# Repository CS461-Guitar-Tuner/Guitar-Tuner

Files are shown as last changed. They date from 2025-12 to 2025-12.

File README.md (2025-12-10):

# Guitar-Tuner
This is the code for our guitar tuner. It can automatically tune a guitar automatically based on which pitch you wish it to be. In addition there is a mode to manually test if the string is in pitch.

This is a makeshift design and thus it is quite costly. This was done more in an attempt to learn how to create a product rather than be efficient.

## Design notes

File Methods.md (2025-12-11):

# Methods

This section describes how the guitar tuner was implemented, including hardware configuration, software architecture, pitch detection logic, user interaction, and motor automation. The goal is to clearly explain both what the system does and how it does it, so that another person could reproduce the prototype using this document.

---

## Hardware Overview and System Architecture

The system uses two microcontrollers:

- **Adafruit Circuit Playground Classic (CPC)** — main controller
- **Adafruit Circuit Playground Bluefruit (CPB)** — motor controller

The Classic handles microphone sampling, pitch detection, OLED display output, button input, and audio feedback. The Bluefruit is dedicated to controlling the tuning motor using PWM. This split prevents motor noise and timing issues from interfering with audio processing.

---

## Pin Assignments and Wiring

### Circuit Playground Classic

The external electret microphone is connected to analog pin A4:

```cpp
const int MIC_PIN = A4;
```

The OLED display (SSD1331) is connected via SPI:

```cpp
#define OLED_MOSI 2
#define OLED_CLK  3
#define OLED_CS   10
#define OLED_DC   9
#define OLED_RST  0
```

The on-board speaker is driven using:

```cpp
#define SPEAKER_PIN 1
```

Motor control signals sent to the Bluefruit:

```cpp
const int MOTOR_DIR_PIN = 12;   // direction
const int MOTOR_EN_PIN  = 6;    // enable
```

User interaction uses the built-in left and right buttons:
- Right button: cycle strings or modes
- Left button: confirm selection / return
- Both buttons held: power on/off

---

### Circuit Playground Bluefruit

Control inputs from the Classic:

```cpp
#define DIR_IN A5
#define EN_IN  A6
```

Motor driver outputs:

```cpp
#define AIN1 A1
#define AIN2 A2
#define SLP  A3
```

The Bluefruit reads direction and enable signals and converts them into PWM outputs that drive the DC motor through a motor driver.

---

## Software Libraries Used

### Circuit Playground Classic
- `math.h` — RMS calculation and logarithmic cents conversion
- `Adafruit_CircuitPlayground.h` — microphone, buttons, speaker
- `SPI.h` — SPI communication
- `Adafruit_SSD1331.h` — OLED driver
- `Adafruit_GFX.h` — graphics rendering
- `Fonts/TomThumb.h` — compact font to reduce memory usage

### Circuit Playground Bluefruit
- `Adafruit_TinyUSB.h` — USB and serial support

Adafruit examples were referenced for OLED setup and hardware initialization. 

---

## Guitar String Representation

Each guitar string is represented by a name and its target frequency:

```cpp
struct Note {
  const char* name;
  float freq;
};

Note strings[] = {
  {"E2", 82.41},
  {"A2", 110.00},
  {"D3", 146.83},
  {"G3", 196.00},
  {"B3", 246.94},
  {"E4", 329.63}
};
```

The currently selected string is changed using the right button.

---

## Pitch Detection and Autocorrelation Logic

The tuner uses a **time-domain autocorrelation-style algorithm** to estimate pitch. This approach was chosen because it is more robust than simple zero-crossing methods for guitar signals, which contain harmonics and background noise.

### Sampling Strategy

```cpp
const int N_SAMPLES = 250;
int16_t samples[N_SAMPLES];
```

The microphone signal is sampled `N_SAMPLES` times using `analogRead()`. The total sampling time is measured using `micros()` so the effective sample rate can be calculated dynamically rather than assumed.

### How Autocorrelation Is Used

1. **DC Offset Removal**  
   The average of all samples is subtracted so the waveform is centered around zero. This prevents bias from affecting pitch estimation.

2. **Noise Rejection (RMS Gate)**  
   The RMS energy of the signal is computed. If the RMS value is below a threshold, the signal is treated as silence and ignored.

3. **Lag Search (Autocorrelation)**  
   The algorithm searches over a range of delays (lags) corresponding to roughly 60–500 Hz, which covers the guitar’s frequency range.  For each lag, it computes the sum of      squared differences between the signal and a shifted version of itself. The lag with the smallest error represents the signal’s fundamental period.

4. **Frequency Calculation**  
   Frequency is computed as the sample rate divided by the best lag.

### Autocorrelation Code

```cpp
float measureFrequency() {
  //  Collect samples and measure sample rate
  unsigned long start = micros(); //take the first time measurement
  for (int i = 0; i < N_SAMPLES; i++) {
    samples[i] = analogRead(MIC_PIN);
  }
  unsigned long end = micros(); //take the second time measurement 
 
  float totalTimeSec = (end - start) / 1000000.0; //find the total time ellapsed in seconds 
  if (totalTimeSec <= 0) return 0.0; //mostly a worry if the timer is wrapping around-- just in case
  float sampleRate = N_SAMPLES / totalTimeSec; //gives us samples per second to be used in frequency calc 
 
  //  Remove DC offset and measure signal energy (centering the signal at zero)
  long sum = 0;
  for (int i = 0; i < N_SAMPLES; i++) {
    sum += samples[i]; //tallying up all of the samples so... 
  }
  float mean = sum / (float)N_SAMPLES; //mean is where the zero lies 
  double energy = 0.0; //reminder about what energy 
  for (int i = 0; i < N_SAMPLES; i++) {
    float v = samples[i] - mean;
    samples[i] = (int16_t)v;
    energy += v * v;
  }
  float rms = sqrt(energy / N_SAMPLES);
 
  // Simple noise gate so we don't react to nothing
  if (rms < 5.0) {   // tweak this threshold if needed
    return 0.0;
  }
 
  // Difference function in guitar range
  int minLag = (int)(sampleRate / 500.0); // ~500 Hz upper bound
  int maxLag = (int)(sampleRate / 60.0);  // ~60 Hz lower bound
 
  if (minLag < 2) minLag = 2;
  if (maxLag >= N_SAMPLES - 1) maxLag = N_SAMPLES - 2;
 
  float bestLag = -1;
  unsigned long bestDiff = 0xFFFFFFFF;
 
  for (int lag = minLag; lag <= maxLag; lag++) {
    unsigned long diff = 0;
 
    for (int i = 0; i < N_SAMPLES - lag; i++) {
      int32_t d = (int32_t)samples[i] - (int32_t)samples[i + lag];
      diff += (unsigned long)(d * d);
    }
 
    if (diff < bestDiff) {
      bestDiff = diff;
      bestLag = lag;
    }
  }
 
  if (bestLag <= 0) return 0.0;
 
  float freq = sampleRate / bestLag;
  return freq;
}
 
float centsOff(float measured, float target) {
  return 1200.0 * log(measured / target) / log(2.0);
}
 
const char* tuningStatus(float cents) {
  if (fabs(cents) < 5.0)  return "IN TUNE";
  if (cents < 0)          return "FLAT";
  return "SHARP";
}
```

---

## Cents Error and Tuning Classification

Pitch error is measured in **cents**, making tuning precision consistent across strings:

```cpp
float centsOff(float measured, float target) {
  return 1200.0 * log(measured / target) / log(2.0);
}
```

```cpp
const char* tuningStatus(float cents) {
  if (fabs(cents) < 5.0)  return "IN TUNE";
  if (cents < 0)          return "FLAT";
  return "SHARP";
}
```
In addition to the RMS noise gate, the tuner ignores detected pitches that are too far from the selected string’s target. Two thresholds are used.
```cpp
const float IN_TUNE_CENTS = 20.0;
const float MAX_DEVIATION_CENTS = 80.0;
```

If the absolute cents error exceeds MAX_DEVIATION_CENTS, the reading is discarded. This prevents background noise, adjacent strings, or unrelated sounds from affecting the display or driving the motor.

---

## State Machine and Modes

```cpp
enum MainState { OFF, WELCOME, SELECT, NORMAL, MOTOR, FORK };
```

- **Normal Mode:** visual tuner with OLED and audio feedback
- **Motor Mode:** automatically adjusts tuning peg
- **Fork Mode:** plays reference tone through speaker

### Motor Automation Logic

```cpp
void sendMotorCommand(float cents) {
  const float DEAD_ZONE = IN_TUNE_CENTS;

  if (fabs(cents) < DEAD_ZONE) {
    digitalWrite(MOTOR_EN_PIN, LOW);   // stop motor
    return;
  }

  bool tighten = (cents < 0);  // FLAT => tighten, SHARP => loosen
  digitalWrite(MOTOR_DIR_PIN, tighten ? HIGH : LOW);
  digitalWrite(MOTOR_EN_PIN, HIGH);
}

```
[Main MCU code](mainMCUcode.ino) |
[Helper MCU code](helperMCUcode.ino) |
[View General Pinout](assets/images/tuner_pinout.pdf) |
[View FSM](assets/images/tuner_fsm.pdf) |
<a href="assets/images/motor_to_peg_adapter.stl" download>3-D Peg Turner (.stl)</a>

---

<html lang="en">
<head>
  <meta charset="UTF-8" />
  <meta name="viewport" content="width=device-width, initial-scale=1.0" />
</head>

<body>

  <h2>Bill of Materials</h2>

  <p>
    These are all the components used throughout the project. 
    Alligator clips and connecting wires were provided.
    3-D printing was provided by Middlebury College.
  </p>

  <p><strong>Total budget:</strong> $150</p>

  <table border="1" cellspacing="0" cellpadding="6">
    <thead>
      <tr>
        <th>Item</th>
        <th>Supplier</th>
        <th>Quantity</th>
        <th>Total Cost</th>
      </tr>
    </thead>
    <tbody>
      <tr>
        <td><a href="https://www.adafruit.com/product/1063">Microphone</a></td>
        <td>Adafruit</td>
        <td>1</td>
        <td>$6.95</td>
      </tr>
      <tr>
        <td><a href="https://www.adafruit.com/product/4227">STEMMA Speaker Amp</a></td>
        <td>Adafruit</td>
        <td>1</td>
        <td>$1.95</td>
      </tr>
      <tr>
        <td><a href="https://www.adafruit.com/product/3777">Micro Servo Motor</a></td>
        <td>Adafruit</td>
        <td>1</td>
        <td>$2.95</td>
      </tr>
      <tr>
        <td><a href="https://www.adafruit.com/product/684">OLED Display</a></td>
        <td>Adafruit</td>
        <td>1</td>
        <td>$29.95</td>
      </tr>
      <tr>
        <td><a href="https://www.digikey.com/en/products/detail/hammond-manufacturing/BH4AAW/3869836">
          4xAA Battery Holder</a></td>
        <td>Digi-Key</td>
        <td>1</td>
        <td>$4.65</td>
      </tr>
      <tr>
        <td><a href="https://learn.adafruit.com/adafruit-circuit-playground-bluefruit">
          Circuit Playground Bluefruit</a></td>
        <td>Adafruit</td>
        <td>1</td>
        <td>$24.95</td>
      </tr>
      <tr>
        <td><a href="https://www.adafruit.com/product/3297">DC Motor Driver</a></td>
        <td>Adafruit</td>
        <td>1</td>
        <td>$5.95</td>
      </tr>
      <tr>
        <td><a href="https://www.adafruit.com/product/3000">Circuit Playground Classic</a></td>
        <td>Adafruit</td>
        <td>1</td>
        <td>$19.95</td>
      </tr>
      <tr>
        <td><strong>Total</strong></td>
        <td>—</td>
        <td>—</td>
        <td><strong>$97.30</strong></td>
      </tr>
    </tbody>
  </table>
</body>
</html>

[Introduction](introduction.md) |
[Methods](Methods.md) |
[Results](results.md) |
[Schedule](schedule.md) |
[Issues](issues.md) |
[Ethics](ethics.md) |
[Accessibility](accessibility.md) |
[References](references.md)

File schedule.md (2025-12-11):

# Planned Team Work Schedule

---

##  Weekly Timeline

### **Week 8**
- Wait for materials to arrive  
- Preemptively read datasheets and pinouts  
- Assemble the circuit board  

### **Weeks 9–10**
- Detect the correct tone  
- Implement a fully functional display  
- Make the motor turn the tuning peg  
- Occasional check-ins to ensure steady progress  

### **Week 11**
- System testing and debugging  

### **Week 12**
- Prepare final demo  
- Write project report  
- Prepare presentation  

---

## Task Breakdown by Responsibility

### **Board Assembly & Hardware Setup**
- Assemble the board  
- Determine how to connect each component by reading datasheets and pinouts  
- Identify correct operating voltages for all components  
- Determine required resistors to achieve target voltages  

---

### **Tone Detection & Signal Processing**
- Detect the correct tone from the guitar string  
- Read microphone input into the Circuit Playground  
- Detect which pitch the user is attempting to tune to  
- Determine whether the current pitch is sharp or flat  
- Communicate pitch information via Serial Port to a laptop as an initial proof of concept  
- Final goal: display pitch information directly on the OLED  

---

### **Display / UI Development (OLED)**
**Edy**

- Program and manage the OLED display  
- Display the detected pitch  
- Use color to indicate how close the tone is to being in tune  
- Show battery life status  

---

### **Motorized Tuning System**
**Gerson & Charlie**

- Automatically turn the motor based on detected pitch (Gerson)  
- Synchronize motor movement to the relative pitch of each string  
- Design a method to activate the motor  
  - Holding a button  
  - Automatic activation via microphone input  

---

### **Testing & Validation**
**Charlie**

- Bring a guitar and a commercial tuner for reference  
- Verify pitch accuracy against a known-good tuner  
- Test accuracy across different pitch ranges  
  - Lower strings  
  - Higher strings
---
 
### **Actuality of the Schedule**
- In the end our schedule ended up changing dramatically throughout the project. We simply met up when we were available and set goals dependant on the day. For example, we would schedule a meeting on simply learning how to turn on the display and work with making the microphone detect pitch. These meetings ended up being around 2-3 hours dependant on the task. There were times in which we were not able to finish the goal by the meeting so we would disperse and end up doing parts by ourselves. We have a fairly efficient workflow overall, however we did struggle a bit with scheduling things near the end due to underestimating certain tasks. Each of us ended up working on most of the components together, even more than expected.
- Edy and Gerson focused a lot of the oled, Gerson with figuring how to turn it on alongside the functionality, while Edy worked a lot on the UI and Gerson helped create a lot of the initial states of our machine.
- The group as a whole didn't figure out whether to use the external microphone or the internal one from the circuit playground till near the end due to the difficulties of making it function with the current setup.
- A lot of time near the end was spent combining the code from the components together to create two different sketches that functioned together without bugs. 

[Introduction](introduction.md) |
[Methods](Methods.md) |
[Results](results.md) |
[Schedule](schedule.md) |
[Issues](issues.md) |
[Ethics](ethics.md) |
[Accessibility](accessibility.md) |
[References](references.md)

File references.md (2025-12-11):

Tripoli, S. et al. (2023) Guide for I2C OLED display with Arduino, Random Nerd Tutorials. Available at: https://randomnerdtutorials.com/guide-for-oled-display-with-arduino/ (Accessed: 10 December 2025).

Rembor, K. Adafruit Circuit Playground Bluefruit, Adafruit Learning System. Available at: https://learn.adafruit.com/adafruit-circuit-playground-bluefruit (Accessed: 10 December 2025).

BH4AAW hammond manufacturing battery products, DigiKey. Available at: https://www.digikey.com/en/products/detail/hammond-manufacturing/BH4AAW/3869836 (Accessed: 10 December 2025).

Industries, A. DC gearbox motor - ‘Tt motor’ - 200RPM - 3 to 6VDC, adafruit industries blog RSS. Available at: https://www.adafruit.com/product/3777 (Accessed: 10 December 2025).

Industries, A. Mini oval speaker with short wires - 8 ohm 1 watt, adafruit industries blog RSS. Available at: https://www.adafruit.com/product/4227 (Accessed: 10 December 2025).

Industries, A. (no date b) Electret microphone amplifier - Max4466 with adjustable gain, adafruit industries blog RSS. Available at: https://www.adafruit.com/product/1063 (Accessed: 10 December 2025).

ChatGPT.” OpenAI, 2025, https://chat.openai.com/

[Introduction](introduction.md) |
[Methods](Methods.md) |
[Results](results.md) |
[Schedule](schedule.md) |
[Issues](issues.md) |
[Ethics](ethics.md) |
[Accessibility](accessibility.md) |
[References](references.md)

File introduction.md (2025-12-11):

# Introduction

The goal of this project is to build a guitar tuner capable of sensing the vibrations of a guitar string and providing clear feedback to the player on whether the string should be tuned higher or lower. Beyond the basic tuning functionality, our team also aims to explore mechanical tuning—automatically twisting the tuning knob—as well as generating a “target tone” that the user can match by ear.

## Motivation

As musicians, we wanted to pursue a project that combined our musical interests with computer science. A guitar tuner offered a practical, compact, and meaningful project that we could see ourselves using in everyday life.  
Gerson plays bass guitar, Charlie plays electric guitar, and Edy sings and plays acoustic guitar, making this project a natural fit for our team’s shared interests.

## Planned Approach

Our tuner will support three distinct modes:

### 1. Standard Pitch Detection Mode  
Similar to a SuperSnark clip-on tuner, the device will detect the pitch of the vibrating string and provide visual feedback indicating whether the note is flat, sharp, or in tune. The user adjusts the tuning knob manually based on the displayed feedback.

### 2. Motor-Assisted Tuning Mode  
In this mode, the user will select the pitch but also activate a motor to automatically twist the guitar’s tuning knob. The motor will turn in the direction needed to bring the string closer to the correct pitch.

### 3. Pitch Fork Tone Mode  
The user will select the string being tuned and play the corresponding target pitch through a speaker. The user can then tune by ear, matching the guitar string to the generated tone.

[Introduction](introduction.md) |
[Methods](Methods.md) |
[Results](results.md) |
[Schedule](schedule.md) |
[Issues](issues.md) |
[Ethics](ethics.md) |
[Accessibility](accessibility.md) |
[References](references.md)

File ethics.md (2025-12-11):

## Ethical and Broader Impact Considerations

One ethical consideration in this project is the environmental impact of the hardware we are using. Our design relies on commercially available components (such as the Circuit Playground board, OLED display, and motor driver) from suppliers like Adafruit and Digi-Key. We do not have direct information about the full sustainability practices of these manufacturers, so we cannot claim that the device is “eco-friendly.” However, we try to reduce unnecessary waste by minimizing the number of parts, using reusable development boards, and designing the system so that components can be repurposed for future projects rather than discarded.

Power consumption and battery use also have environmental implications. Since the tuner is battery-powered, frequent battery replacement could contribute to electronic waste. As part of our design, we aim to keep the device’s power draw relatively low and encourage proper recycling or reuse of batteries and components after the project’s lifetime.

Another consideration is user privacy. Although this tuner processes audio signals from the guitar, our design does not store recordings, transmit data to external services, or log user information. All processing happens locally on the microcontroller, and there is no network connectivity. This reduces the risk of misuse of personal data or audio recordings and keeps the interaction between the user and the device self-contained.

Overall, while this is a small-scale class project, we acknowledge that hardware design has environmental and privacy implications, and we have tried to make choices that are transparent, minimally wasteful, and respectful of user data.

[Introduction](introduction.md) |
[Methods](Methods.md) |
[Results](results.md) |
[Schedule](schedule.md) |
[Issues](issues.md) |
[Ethics](ethics.md) |
[Accessibility](accessibility.md) |
[References](references.md)

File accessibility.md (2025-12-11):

## Accessibility Considerations

Accessibility was an important consideration in the design of this project. In addition to visual feedback on the display, the tuner provides audio cues to assist users who may be visually impaired. With this being said, due to the data restrictions that we encountered while coding, we were not able to use multiple fonts. The font at the current moment isn't able to change and thus it is quite small which might prove difficult for those with bad eye sight. To make up for this in particular, the reference tone mode allows users to tune their instrument by ear without relying on the screen. 

The motor-assisted tuning feature would theoretically supports users with limited fine motor control by reducing the need for precise manual adjustments of the tuning pegs. By automating small tuning movements, the device can help make the tuning process more accessible and less physically demanding. With it's current implementation the motor itself is too weak to fully tune the guitar. In the future it is likely a different motor can be used in order to fully rotate the dials on the strings.

Together, these features aim to make the tuner usable by a wider range of players with varying sensory and motor abilities.

[Introduction](introduction.md) |
[Methods](Methods.md) |
[Results](results.md) |
[Schedule](schedule.md) |
[Issues](issues.md) |
[Ethics](ethics.md) |
[Accessibility](accessibility.md) |
[References](references.md)

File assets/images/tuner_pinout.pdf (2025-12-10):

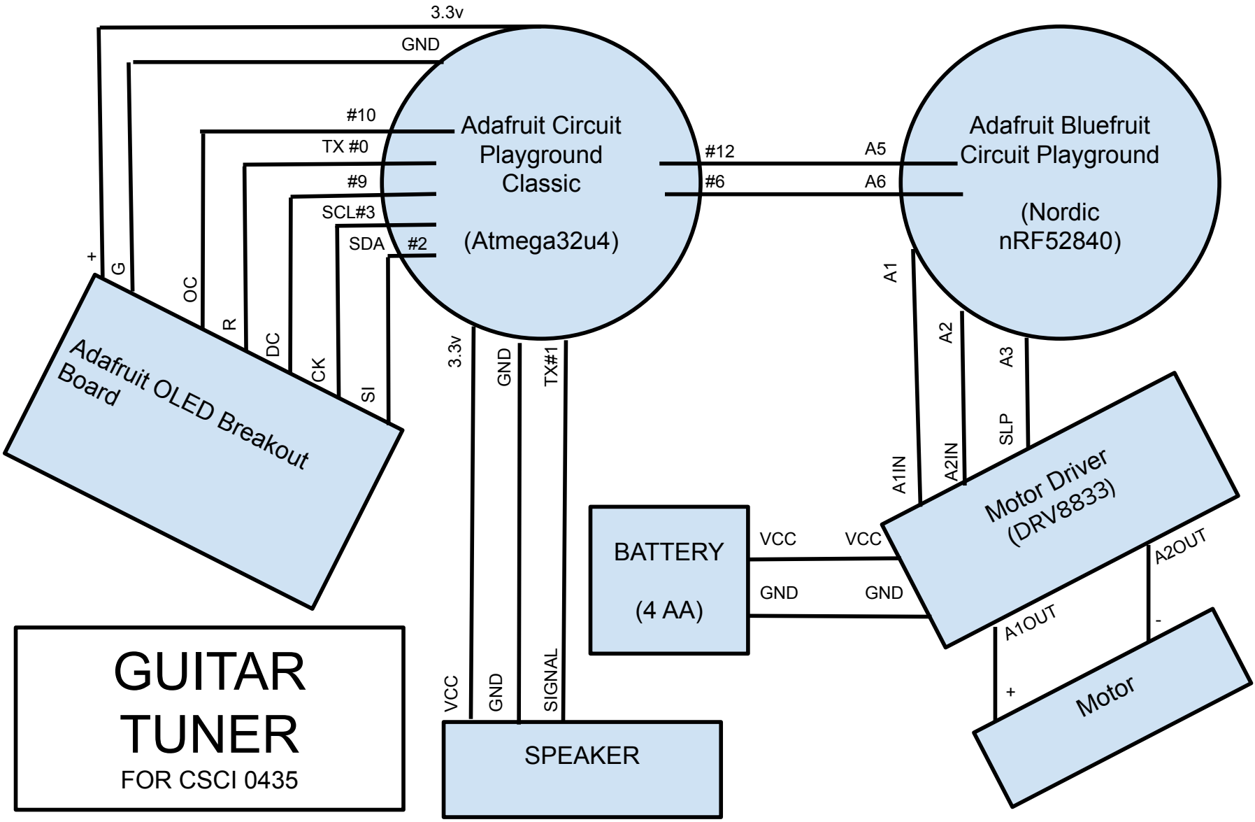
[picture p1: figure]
Adafruit Circuit Playground Classic; (Atmega32u4); Adafruit Bluefruit Circuit Playground; (Nordic nRF52840); Adafruit OLED Breakout Board; SCL#3; SDA; GND; Motor Driver (DRV8833); Motor; BATTERY; VCC; A1OUT; A2OUT; SLP; SPEAKER; GND GND; SIGNAL TX#1; GUITAR TUNER; FOR CSCI 0435

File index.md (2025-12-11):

# Guitar Tuner Project

---

## Welcome

This website contains the documentation for our Guitar Tuner Project.  
Each page covers a different part or our process.

Use the links below to navigate through the project.

---

## Meet the Team!

<style>
.team-table img {
  width: 180px;
  height: 220px;
  object-fit: cover;
  border-radius: 6px;
}
.team-table td {
  padding: 8px 16px;
}
</style>

<table class="team-table">
  <tr>
    <td align="center">
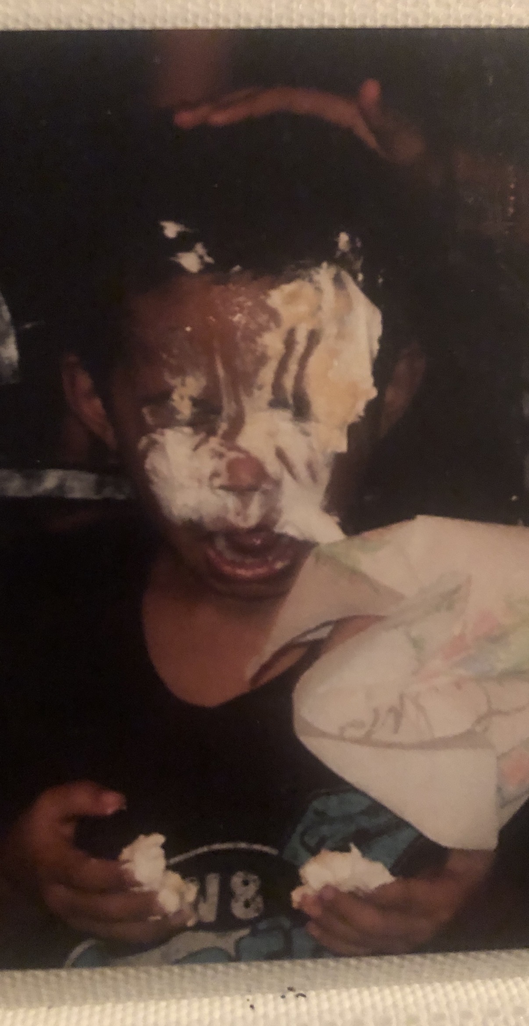
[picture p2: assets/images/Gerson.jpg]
Gerson
      
      <br />
      <strong>Gerson H</strong>
    </td>
    <td align="center">
      Charlie
      <br />
      <strong>Charlie G</strong>
    </td>
    <td align="center">
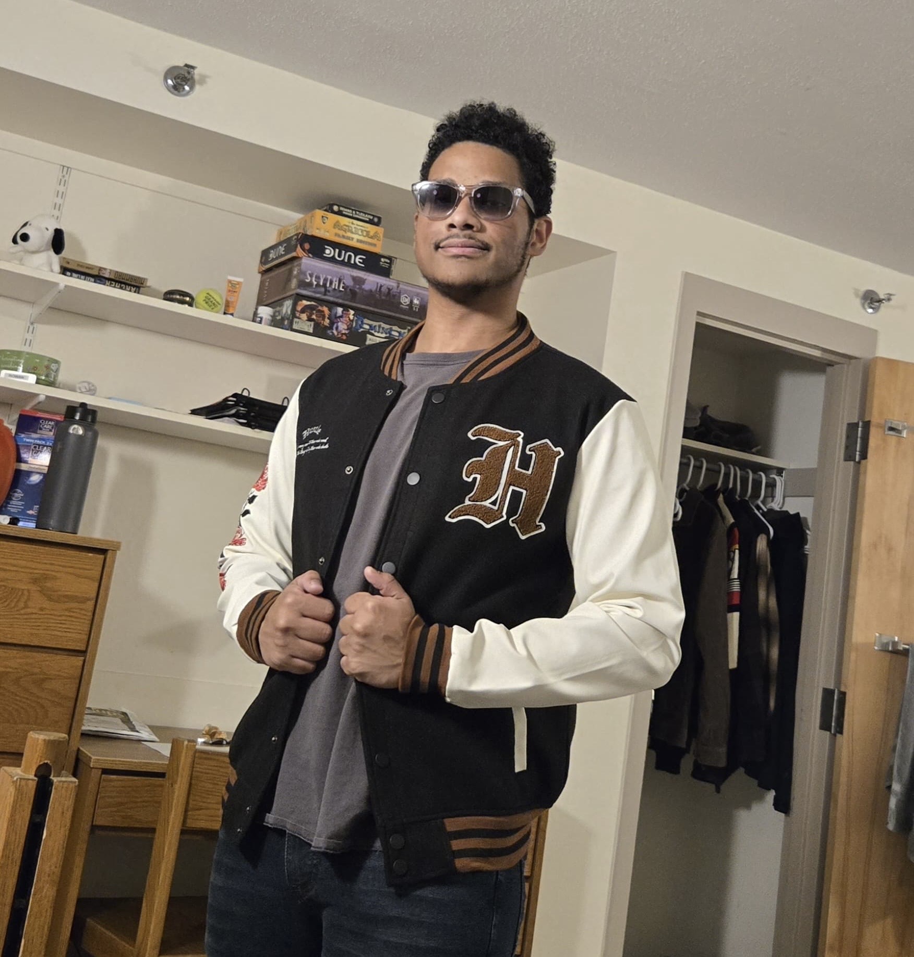
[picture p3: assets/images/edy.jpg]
Edy
      
      <br />
      <strong>Edy C</strong>
    </td>
    <td align="center">
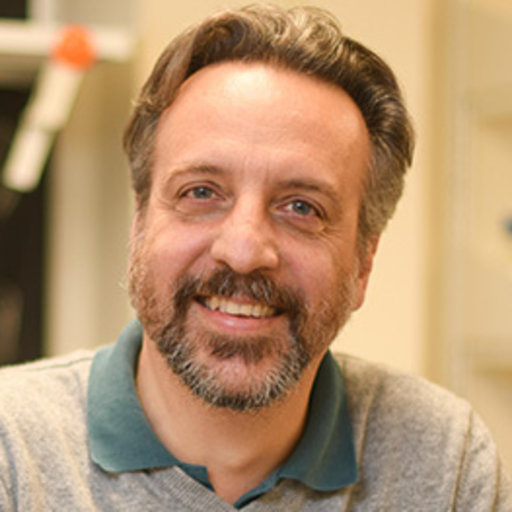
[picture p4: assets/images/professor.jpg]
Professor Vaccari
      
      <br />
      <strong>Professor Vaccari</strong>
    </td>
  </tr>
</table>

---

## Project Pages

[Introduction](introduction.md) |
[Methods](Methods.md) |
[Results](results.md) |
[Schedule](schedule.md) |
[Issues](issues.md) |
[Ethics](ethics.md) |
[Accessibility](accessibility.md) |
[References](references.md)

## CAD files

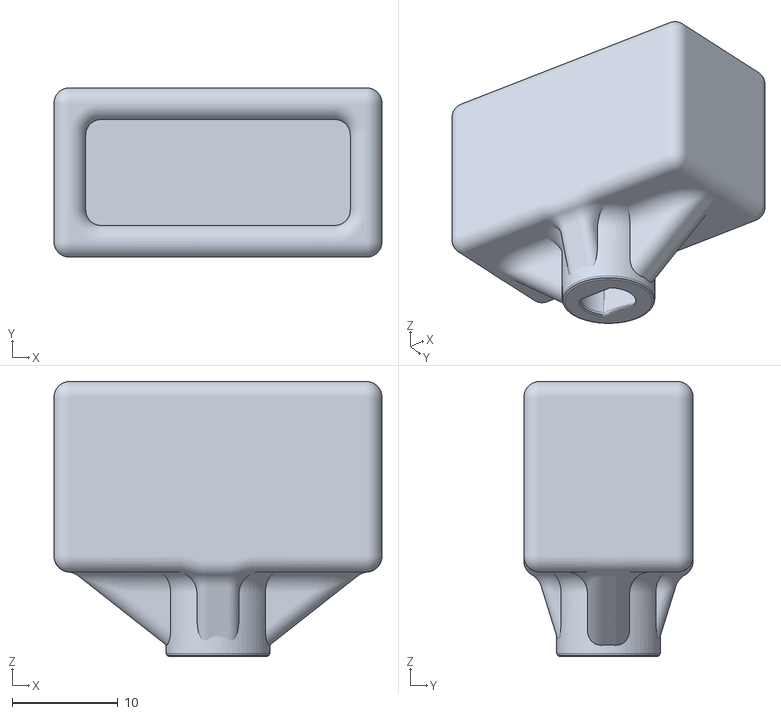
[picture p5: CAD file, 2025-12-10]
assets/images/motor_to_peg_adapter.stl
31.0 x 16.0 x 26.0

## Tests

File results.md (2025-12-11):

<style>
  .img-wrap {
    text-align: center;
    margin: 20px 0;
  }
  .img-wrap img {
    width: 350px;    
    border-radius: 6px; 
    box-shadow: 0 0 8px rgba(0,0,0,0.15);
  }
</style>

The guitar tuner starts off. When both the right and left buttons are pressed it boots up into the title screen. At any point the user can press left and right buttons in order to turn off the tuner.

<div class="img-wrap">
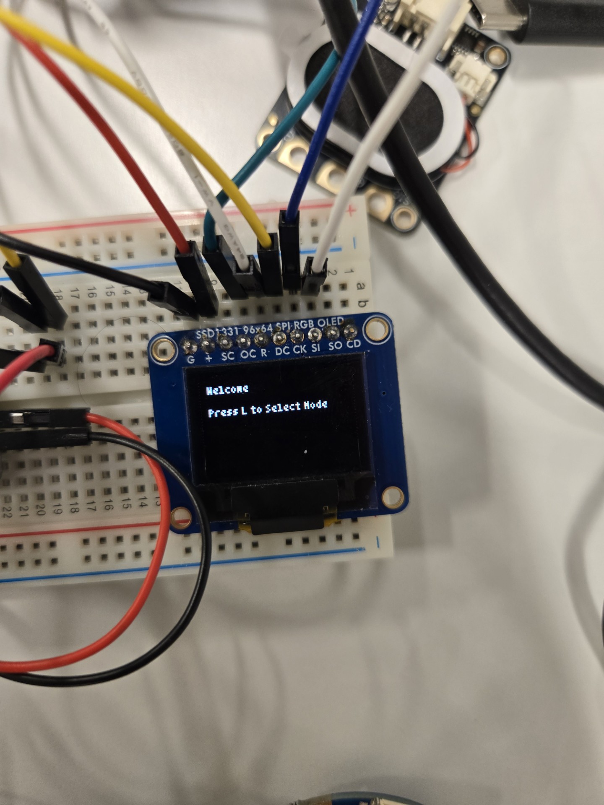
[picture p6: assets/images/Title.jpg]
  
</div>

During this mode, if L is pressed it goes into selection mode which allows for three different options, normal, tuning fork and motor modes. When L is pressed during selection mode, it comfirms the mode. If L is pressed during any of these modes it goes back to allow for the user to select a different mode.

<div class="img-wrap">
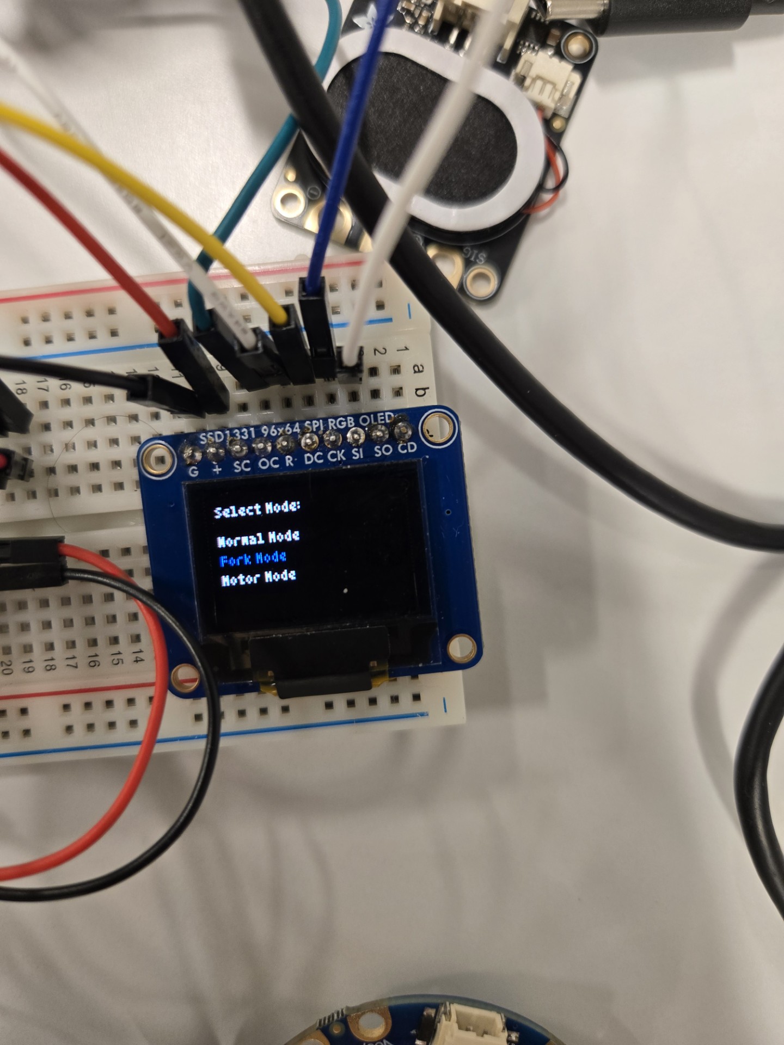
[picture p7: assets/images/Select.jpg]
  
</div>

Normal Mode allows the user to to select a note and tune the guitar string accordingly. We are assuming that each string is relatively close to its actual tone, so in order to improve oled performance any "cents" way above the notes range is ignored. There are also audio cues for when a note is in tune.

<div class="img-wrap">
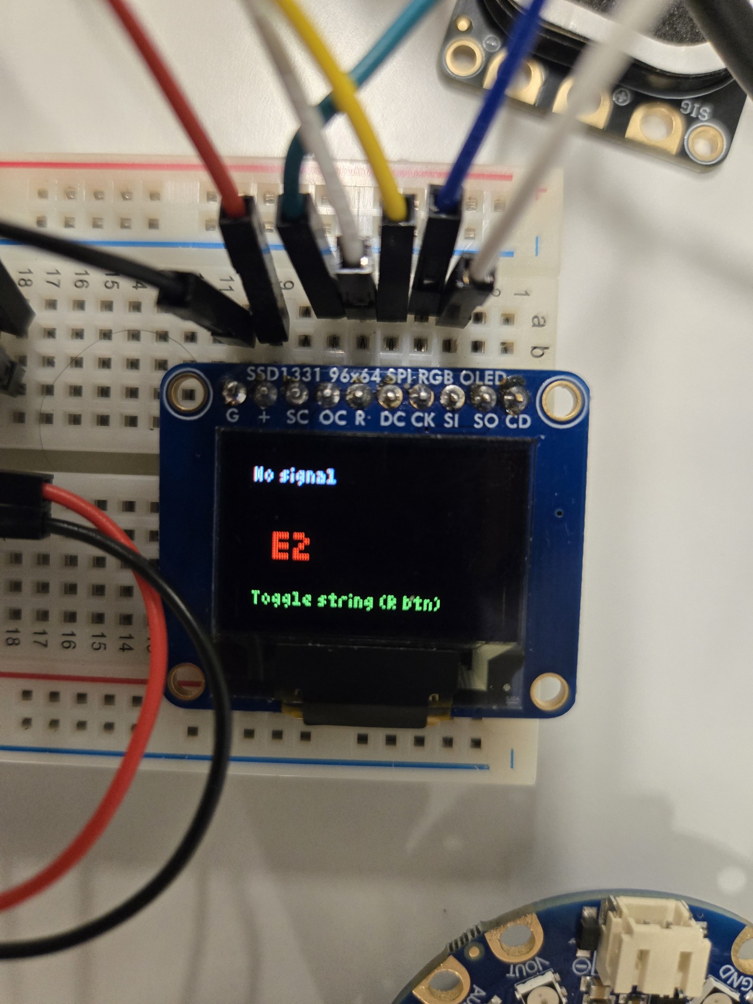
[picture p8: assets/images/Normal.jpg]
  
</div>

Tuning Fork Mode uses the speaker to its fullest potential by playing a tone that matches the note displaced on screen. This mode is very manual as it is meant to be used for the user to tune the guitar using their ears and sense of pitch by playing it out loud.

<div class="img-wrap">
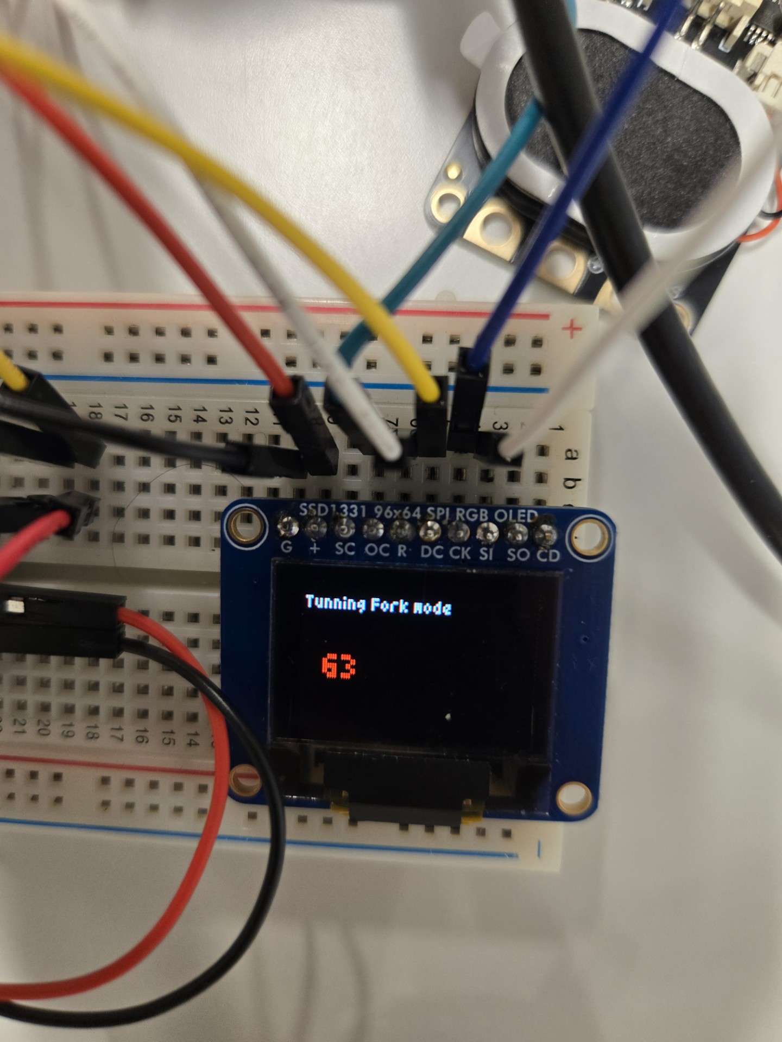
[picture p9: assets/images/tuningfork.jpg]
  
</div>

Motor Mode theroetically allows for the user to automatically tune the guitar based on which note is on the current screen. The motor and the driver are in charge of this task. At the current moment however the motor itself is too weak to push the pegs even if it would currently be in the correct direction to tune it.

<div class="img-wrap">
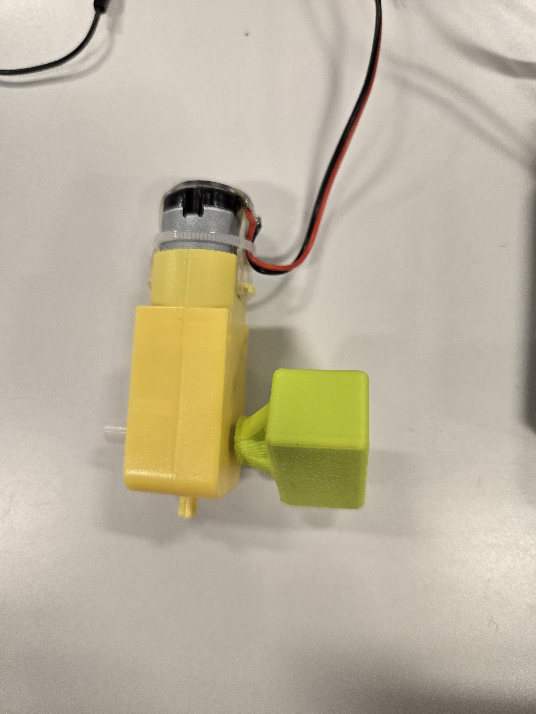
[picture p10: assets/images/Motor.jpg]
  
</div>

This is the full setup!
<div class="img-wrap">
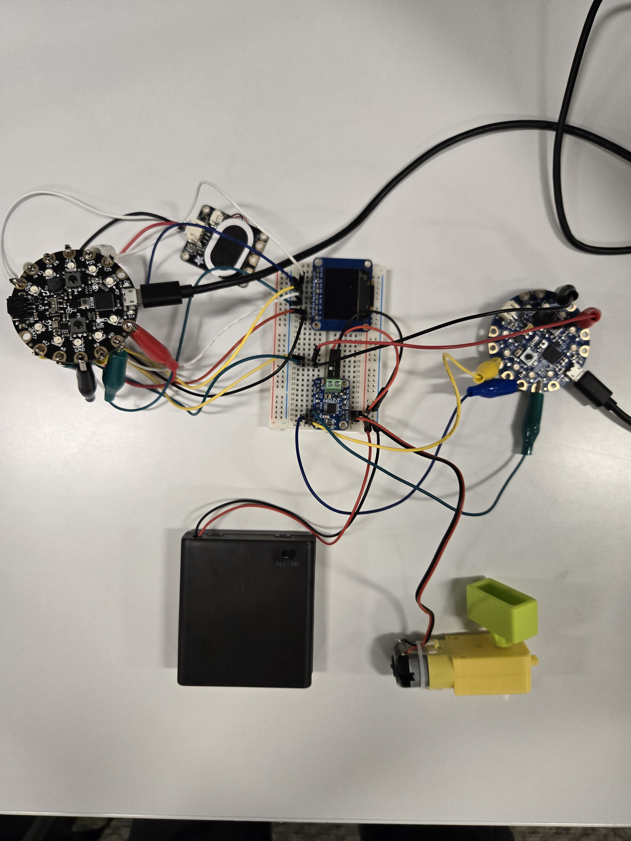
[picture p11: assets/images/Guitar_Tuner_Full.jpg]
  
</div>

[Introduction](introduction.md) |
[Methods](Methods.md) |
[Results](results.md) |
[Schedule](schedule.md) |
[Issues](issues.md) |
[Ethics](ethics.md) |
[Accessibility](accessibility.md) |
[References](references.md)

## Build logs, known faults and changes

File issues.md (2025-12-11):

# Issues and Challenges

## Microphone Reliability

One of the first issues we encountered was a faulty external microphone. While we were able to get it working intermittently, the connection was unreliable and required frequent troubleshooting. Because this significantly slowed development, we ultimately decided to switch to using the internal microphone on the Circuit Playground Classic. Although the internal microphone had some limitations, it proved to be much more stable and allowed us to continue development without constant hardware issues.

---

## Pitch Detection Difficulties

Pitch detection required substantial experimentation and iteration. Our initial approach attempted to use a frequency-domain correlation-based method, but this approach was highly sensitive to background noise and produced unstable results in non-ideal environments. Because of this, it was difficult to reliably isolate the fundamental frequency of the guitar string.

We eventually transitioned to an autocorrelation-based pitch detection method, which proved to be more robust for monophonic signals like individual guitar strings. Although this approach still required careful parameter tuning, it significantly improved pitch stability and accuracy compared to our initial method.

---

## OLED Display Configuration

Configuring the OLED display presented another major challenge. Documentation and datasheets for the display and the Circuit Playground pinouts were sometimes inconsistent or unclear, making it difficult to determine correct wiring and configuration. As a result, the display did not work initially.

Through trial, error, and systematic experimentation, we were able to determine a working pin configuration and successfully initialize the display. Once correctly configured, the OLED performed reliably and became a central part of the user interface.

---

## Program Storage Limitations

The Circuit Playground Classic has a very limited amount of program storage, which imposed constraints on software complexity. As the project grew, we encountered compilation failures due to insufficient memory.

To address this, we removed unused fonts, reduced display assets, and eliminated non-essential code paths. These trade-offs allowed us to retain core functionality—pitch detection, display output, and motor control—while staying within the available memory limits.

---

## Motor Strength

The motor was a component that we wished to use from the start, that being said, one thing that we didn't calculate was how strong our motor eneded to be to tune the pegs of a guitar. As it is currently, the motor doesn't have nearly enough strength to tune a guitar which is quite important for accessibility. 

Even if it does detect the current pitch and moves based on that due to the lacking strength of the components it does not work for it's current purpose.

---

Overall, these challenges shaped the final design of the project and required us to make practical engineering trade-offs between functionality, reliability, and hardware constraints.

[Introduction](introduction.md) |
[Methods](Methods.md) |
[Results](results.md) |
[Schedule](schedule.md) |
[Issues](issues.md) |
[Ethics](ethics.md) |
[Accessibility](accessibility.md) |
[References](references.md)

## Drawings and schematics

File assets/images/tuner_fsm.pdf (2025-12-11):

# GUITAR TUNER

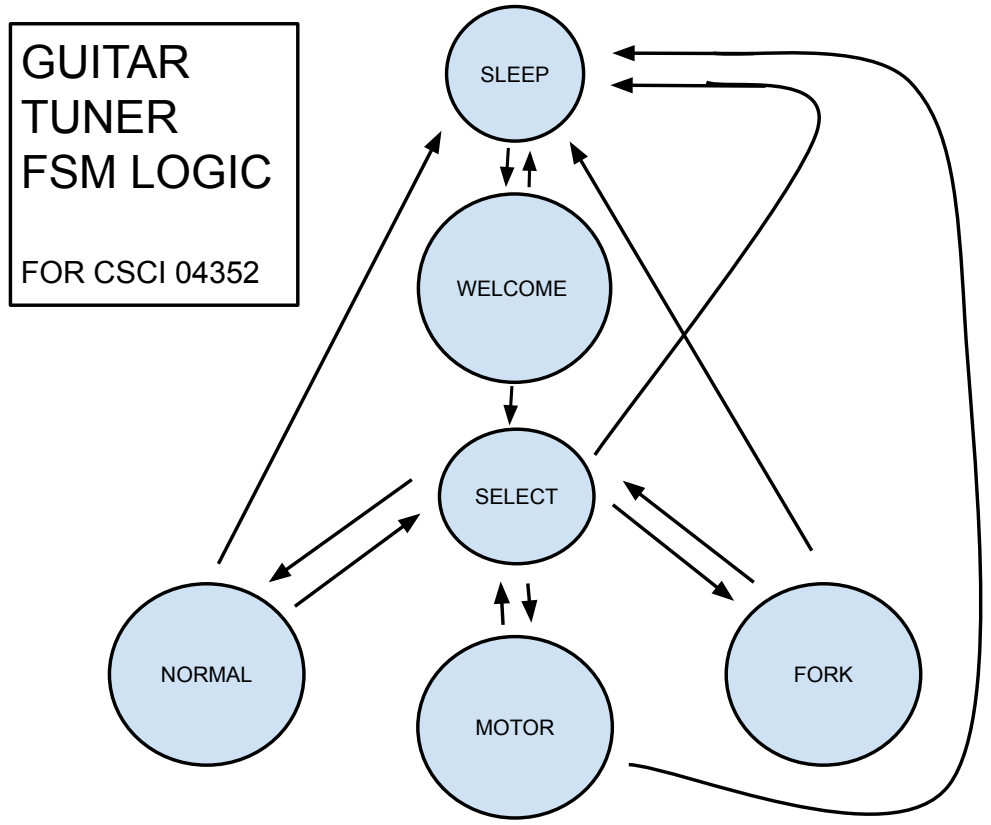
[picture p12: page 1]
SLEEP; FORK; MOTOR; NORMAL; SELECT; FSM LOGIC; FOR CSCI 04352; WELCOME

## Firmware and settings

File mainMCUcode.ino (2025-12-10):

/*========================================================================================================================================================*/
/*========================================================================================================================================================*/
/*========================================================================================================================================================*/
/*

TABLE OF CONTENTS:
0) DEPENDENCIES
1) DECLARATIONS, HELPER PROTOTYPES, AND GENERAL SET UP 
2) MAJOR FUNCTION PROTOTYPES
3) SET UP
4) LOOP (MAIN)
5) ACTUAL HELPER FUNCTIONS, IN ORDER OF PROTOTYPE APPEARANCE
6) ACTUAL MAJOR FUNCTIONS, IN ORDER OF PROTOTYPE APPEARANCE

*/
/*========================================================================================================================================================*/
/*========================================================================================================================================================*/
/*========================================================================================================================================================*/
/* 0 DEPENDENCIES*/

#include <math.h> //for DSP
//#include <Adafruit_TinyUSB.h>
#include <Adafruit_CircuitPlayground.h> //for convinent functions 

/*Libraries related to the display.*/
#include <SPI.h> //the graphics driver library is built on SPI
#include <Adafruit_SSD1331.h> //used for low level Display Functions and GFX is built on this
#include <Adafruit_GFX.h> //high level display library 
#include <Fonts/TomThumb.h> //Fonts for display
//#include <Fonts/FreeMono9pt7b.h> //Fonts for display
/*========================================================================================================================================================*/
/*========================================================================================================================================================*/
/*========================================================================================================================================================*/
/* 1 DECLARATIONS, HELPER PROTOTYPES, AND GENERAL SET UP */

        
/*-----------------------TUNER CONFIG AND GUITAR STRING STRUCT---------------------------------------------------------*/
const int MIC_PIN    = A4;     // external mic on A4
const int N_SAMPLES  = 250;   // larger window = more accurate low notes
int16_t samples[N_SAMPLES];

struct Note {
  const char* name;
  float freq;
};
 
Note strings[] = { //These are the pitches and frequencies of the six different guitar strings. 
  {"E2", 82.41},
  {"A2", 110.00},
  {"D3", 146.83},
  {"G3", 196.00},
  {"B3", 246.94},
  {"E4", 329.63}
};

const int NUM_STRINGS = sizeof(strings) / sizeof(strings[0]);
int currentStringIndex = 0;   // which string we’re tuning (0 = E2, ...)
int lastStringDrawn = -1;     // track OLED state
bool rightPrevFORK = false;        // for edge-detect

/*-----------------------OLED PINS AND THROTTLING OLED & SERIAL---------------------------------------------------------*/
#define OLED_CS   10
#define OLED_DC   9
#define OLED_RST  0
#define OLED_MOSI 2    
#define OLED_CLK  3  

Adafruit_SSD1331 oled(OLED_CS, OLED_DC, OLED_MOSI, OLED_CLK, OLED_RST);

char lastNoteName[4]     = "---";
char lastStatus[10]      = "";
int  lastCentsRounded    = 9999;
int  lastHzRounded       = 0;
bool lastHadSignal       = false;
unsigned long lastPrintMs = 0;



 /*-----------------------PITCH/FREQUENCY MATH FUNCTIONS---------------------------------------------------------*/
// how wide the “good enough” band is
const float IN_TUNE_CENTS       = 20.0;   // same as motor mode (you can drop to 10.0 if you want tighter)
// how far we’re willing to accept a reading from the target note at all
const float MAX_DEVIATION_CENTS = 80.0;   // reject anything further away

bool wasInTune = false;            // for in-tune beep edge
float measureFrequency();
float centsOff(float measured, float target);
const char* tuningStatus(float cents);



 /*-----------------------OLED DRAWING HELPERS---------------------------------------------------------*/
void drawNoSignal();
void drawTuningScreen(const char* noteName, int hzRounded, int centsRounded, const char* status);

void drawCurrentNoteScreen(); //used in fork

 /*-----------------------SPEAKER SET UP & AUDIO HELPERS---------------------------------------------------------*/
#define SPEAKER_PIN 1
void playInTuneBeepIfNeeded(bool inTune);
void playCurrentNotePulse();


 /*-----------------------BUTTON SETUP/TOGGLING HELPERS---------------------------------------------------------*/
bool rightPrev = false;            // to be used in handle right button for toggling
void handleRightButton();

bool firstTime = true; //first time going through normal to get screen to display
bool firstTimeMotor = true; //first time going through motor to get screen to display
bool firstTimeFork = true; //first time going through fork to get screen to display



// ---------- MOTOR CONTROL PINS/MOTOR SET UP----------
const int MOTOR_DIR_PIN = 12;   // HIGH = tighten, LOW = loosen //PINS LINKED UP TO BLUE FRUIT
const int MOTOR_EN_PIN  = 6;    // HIGH = motor on, LOW = motor off

void sendMotorCommand(float cents);

/*------------------------------------------------SELECTION SET UP------------------------------------------------*/ 
int selected_Mode = 0; //for selected mode

/*------------------------------------------------MAIN FSM SET UP------------------------------------------------*/ 
enum MainState {OFF, 
WELCOME, 
SELECT, 
NORMAL, 
MOTOR, 
FORK};
MainState state = OFF;
MainState next_state = OFF;


/*========================================================================================================================================================*/
/*========================================================================================================================================================*/
/*========================================================================================================================================================*/
/* 2 MAJOR FUNCTION PROTOTYPES*/

void normal();
void motor();
void fork();
void Title_Screen();
void Selection_Mode();


/*========================================================================================================================================================*/
/*========================================================================================================================================================*/
/*=======================================================================================================================================================*/
/* 3 SET UP*/

void setup() {
  //for circut playground library
  CircuitPlayground.begin();

  pinMode(LED_BUILTIN, OUTPUT); //for debugging
  pinMode(SPEAKER_PIN, OUTPUT);

  pinMode(MOTOR_DIR_PIN, OUTPUT);
  pinMode(MOTOR_EN_PIN, OUTPUT);
  digitalWrite(MOTOR_DIR_PIN, LOW);
  digitalWrite(MOTOR_EN_PIN, LOW);
 
  //OLED SET UP
  oled.begin();
  oled.fillScreen(0x0000);
  oled.setRotation(0);
  oled.setFont(&TomThumb);
  oled.setTextSize(1);
  oled.setTextColor(0xFFFF);
  oled.setCursor(2, 10);
  oled.setCursor(2, 25);
  
}

/*========================================================================================================================================================*/
/*========================================================================================================================================================*/
/*=======================================================================================================================================================*/
/*4 LOOP (MAIN)*/

void loop() {
  switch(state){
    case OFF:// OFF STATE
        if (onOff()){ //Left button is held for 5 sec, it turns on. 
          next_state = WELCOME;
          
        }
      break;

    case WELCOME://WELCOME STATE
        Title_Screen();
        if (CircuitPlayground.leftButton()){ //Right button advances to the select state. 
          next_state = SELECT;
        }
      break; 

    case SELECT: //SELECT STATE
        if (CircuitPlayground.rightButton()) { 
          selected_Mode++;
          if (selected_Mode > 2){
            selected_Mode = 0;
          }
        }
        Selection_Mode();
        if(CircuitPlayground.leftButton()){ //next state is made base on user choice in this state. 
            if (selected_Mode==0){// Normal
              next_state = NORMAL;
            }else if (selected_Mode==1){// Fork 
              next_state = FORK;
            }else if (selected_Mode==2){//Motor
              next_state = MOTOR;
            }
        }
      break;

    case NORMAL: //MODE ONE: NORMAL STATE
        normal();
        
        if (CircuitPlayground.leftButton()){
          next_state = SELECT;
        }
      break;

    case MOTOR: //MODE TWO: MOTOR STATE
        motor();
        if (CircuitPlayground.leftButton()){
          next_state = SELECT;
        }
      break;

    case FORK: //MODE THREE: FORK STATE
        fork();
        if (CircuitPlayground.leftButton()){
          next_state = SELECT;
          oled.setTextSize(1); 
        }
      break;
  }
  if (onOff()){ //hold both buttons to turn 
          next_state = OFF;
  }if (state != next_state) {
    oled.fillScreen(0x0000);
  }

  state = next_state;
}
/*========================================================================================================================================================*/
/*========================================================================================================================================================*/
/*=======================================================================================================================================================*/
/*5 ACTUAL HELPER FUNCTIONS, IN ORDER OF PROTOTYPE APPEARANCE*/
bool onOff(){
  if(CircuitPlayground.leftButton() && CircuitPlayground.rightButton()){
    return true;
  }else{
    return false;
  }
}
 /*-----------------------PITCH/FREQUENCY MATH FUNCTIONS---------------------------------------------------------*/
float measureFrequency() {
  // 1) Collect samples and measure sample rate
  unsigned long start = micros(); //take the first time measurement
  for (int i = 0; i < N_SAMPLES; i++) {
    samples[i] = analogRead(MIC_PIN);
  }
  unsigned long end = micros(); //take the second time measurement 
 
  float totalTimeSec = (end - start) / 1000000.0; //find the total time ellapsed in seconds 
  if (totalTimeSec <= 0) return 0.0; //mostly a worry if the timer is wrapping around-- just in case
  float sampleRate = N_SAMPLES / totalTimeSec; //gives us samples per second to be used in frequency calc 
 
  // 2) Remove DC offset and measure signal energy (centering the signal at zero)
  long sum = 0;
  for (int i = 0; i < N_SAMPLES; i++) {
    sum += samples[i]; //tallying up all of the samples so... 
  }
  float mean = sum / (float)N_SAMPLES; //mean is where the zero lies 
  double energy = 0.0; //reminder about what energy 
  for (int i = 0; i < N_SAMPLES; i++) {
    float v = samples[i] - mean;DC
    samples[i] = (int16_t)v;
    energy += v * v;
  }
  float rms = sqrt(energy / N_SAMPLES);
 
  // Simple noise gate so we don't react to nothing
  if (rms < 5.0) {   // tweak this threshold if needed
    return 0.0;
  }
 
  // 3) Difference function in guitar range
  int minLag = (int)(sampleRate / 500.0); // ~500 Hz upper bound
  int maxLag = (int)(sampleRate / 60.0);  // ~60 Hz lower bound
 
  if (minLag < 2) minLag = 2;
  if (maxLag >= N_SAMPLES - 1) maxLag = N_SAMPLES - 2;
 
  float bestLag = -1;
  unsigned long bestDiff = 0xFFFFFFFF;
 
  for (int lag = minLag; lag <= maxLag; lag++) {
    unsigned long diff = 0;
 
    for (int i = 0; i < N_SAMPLES - lag; i++) {
      int32_t d = (int32_t)samples[i] - (int32_t)samples[i + lag];
      diff += (unsigned long)(d * d);
    }
 
    if (diff < bestDiff) {
      bestDiff = diff;
      bestLag = lag;
    }
  }
  if (bestLag <= 0) return 0.0;
  float freq = sampleRate / bestLag;
  return freq;
}
float centsOff(float measured, float target) {
  return 1200.0 * log(measured / target) / log(2.0);
}
const char* tuningStatus(float cents) {
  if (fabs(cents) < 5.0)  return "IN TUNE";
  if (cents < 0)          return "FLAT";
  return "SHARP";
}
/*-----------------------OLED DRAWING HELPERS---------------------------------------------------------*/
void drawNoSignal() {
  oled.fillScreen(0x0000);

  oled.setTextSize(1);
  oled.setTextColor(0xFFFF);
  oled.setCursor(2, 10);
  oled.print("No signal");

  // Big target note in center
  oled.fillRect(0, 16, 96, 32, 0x0000);
  oled.setTextSize(2);
  oled.setTextColor(0xF800);   // red
  oled.setCursor(10, 40);
  oled.print(strings[currentStringIndex].name);

  // Bottom hint
  oled.fillRect(0, 48, 96, 16, 0x0000);
  oled.setTextSize(1);
  oled.setTextColor(0x07E0);
  oled.setCursor(2, 58);
  oled.print("Toggle string (R btn)");

  strcpy(lastNoteName, "---");
  strcpy(lastStatus, "");
  lastCentsRounded = 9999;
  lastHzRounded = 0;
}

// note screen during tuning
void drawTuningScreen(const char* noteName, int hzRounded, int centsRounded, const char* status) {
  // Top: frequency
  oled.fillRect(0, 0, 96, 16, 0x0000);
  oled.setTextSize(1);
  oled.setCursor(2, 10);
  oled.setTextColor(0x07E0); // green-ish
  oled.print("Freq: ");
  oled.print(hzRounded);
  oled.print(" Hz");

  // Middle: big note
  oled.fillRect(0, 16, 96, 32, 0x0000);
  oled.setTextSize(2);
  oled.setCursor(10, 40);
  oled.setTextColor(0xF800);
  oled.print(noteName);

  // Bottom: cents + status
  oled.fillRect(0, 48, 96, 16, 0x0000);
  oled.setTextSize(1);
  oled.setCursor(2, 58);
  oled.setTextColor(0xFFFF);
  oled.print(centsRounded);
  oled.print(" cents ");
  oled.print(status);
}
void drawCurrentNoteScreen() { //used in fork 
  oled.fillScreen(0x0000);

  // Top: mode label
  oled.setTextSize(1);
  oled.setTextColor(0xFFFF);
  oled.setCursor(2, 10);
  oled.print("Tunning Fork mode");

  // Middle: big note name (E2, A2, etc.)
  oled.fillRect(0, 16, 96, 32, 0x0000);
  oled.setTextSize(2);
  oled.setTextColor(0xF800);   // red
  oled.setCursor(10, 40);
  oled.print(strings[currentStringIndex].name);

 
  lastStringDrawn = currentStringIndex;
}

 /*-----------------------SPEAKER MODE SET UP & AUDIO HELPERS---------------------------------------------------------*/
void playInTuneBeepIfNeeded(bool inTune) {
  if (inTune && !wasInTune) {
    tone(SPEAKER_PIN, 1200, 150);
  }
  wasInTune = inTune;
}

void playCurrentNotePulse() {
  int f = strings[currentStringIndex].freq;

  // A slightly smoother pulse: longer tone, longer pause
  tone(SPEAKER_PIN, f);
  delay(700);     // tone duration
  noTone(SPEAKER_PIN);
  delay(350);     // pause between pulses
}

 /*-----------------------BUTTON SETUP/TOGGLING HELPERS---------------------------------------------------------*/
void handleRightButton() {
  bool rightNow = CircuitPlayground.rightButton();

  if (rightNow && !rightPrev) {
    currentStringIndex++;
    if (currentStringIndex >= NUM_STRINGS) currentStringIndex = 0;

    tone(SPEAKER_PIN, 1500, 50);   // click

    strcpy(lastNoteName, "---");
    lastHadSignal = false;

    // Immediately show new target even if silent
    drawNoSignal();
  }

  rightPrev = rightNow;
}
// ---------- MOTOR CONTROL PINS/MOTOR SET UP----------
void sendMotorCommand(float cents) {
  const float DEAD_ZONE = IN_TUNE_CENTS;

  if (fabs(cents) < DEAD_ZONE) {
    digitalWrite(MOTOR_EN_PIN, LOW);   // stop motor
    return;
  }
  bool tighten = (cents < 0);  // FLAT => tighten, SHARP => loosen
  digitalWrite(MOTOR_DIR_PIN, tighten ? HIGH : LOW);
  digitalWrite(MOTOR_EN_PIN, HIGH);
}

/*========================================================================================================================================================*/
/*========================================================================================================================================================*/
/*=======================================================================================================================================================*/
/*6 ACTUAL MAJOR FUNCTIONS, IN ORDER OF PROTOTYPE APPEARANCE*/

void normal() {
  //bool firstTime = true;
  handleRightButton();
  
  float hz = measureFrequency();
  unsigned long now = millis();
  
  if (hz > 30.0 && hz < 1000.0) {
    Note target = strings[currentStringIndex];
    float cents = centsOff(hz, target.freq);

    if (fabs(cents) > MAX_DEVIATION_CENTS) {
      playInTuneBeepIfNeeded(false);
      return;
    }

    const char* status = tuningStatus(cents);
    bool inTune = (fabs(cents) < IN_TUNE_CENTS);
    int hzRounded    = (int)(hz + 0.5);
    int centsRounded = (int)(cents + (cents >= 0 ? 0.5 : -0.5));

    // audio
    playInTuneBeepIfNeeded(inTune);

    bool changed = true; 
    if (changed) {
      drawTuningScreen(target.name, hzRounded, centsRounded, status);

      strcpy(lastNoteName, target.name);
      strcpy(lastStatus, status);
      lastCentsRounded = centsRounded;
      lastHzRounded    = hzRounded;
      lastHadSignal    = true;
    }
    changed =
      (strcmp(target.name, lastNoteName) != 0) ||
      (strcmp(status,      lastStatus)   != 0) ||
      (centsRounded != lastCentsRounded) ||
      (hzRounded    != lastHzRounded)    ||
      !lastHadSignal;
  } else {
    // no valid frequency
    playInTuneBeepIfNeeded(false);
    //
    if (lastHadSignal||firstTime) {
      drawNoSignal();
      lastHadSignal = false;

      if (now - lastPrintMs > 200) {
        lastPrintMs = now;
      }
    }
  }
  firstTime = false; 
}
void motor() {
  handleRightButton();

  float hz = measureFrequency();
  unsigned long now = millis();

  if (hz > 30.0 && hz < 1000.0) {
    Note target = strings[currentStringIndex];
    float cents = centsOff(hz, target.freq);

    // Ignore stuff way off target note
    if (fabs(cents) > MAX_DEVIATION_CENTS) {
      sendMotorCommand(0.0);
      playInTuneBeepIfNeeded(false);
      return;
    }

    const char* status = tuningStatus(cents);
    bool inTune = (fabs(cents) < IN_TUNE_CENTS);

    int hzRounded    = (int)(hz + 0.5);
    int centsRounded = (int)(cents + (cents >= 0 ? 0.5 : -0.5));

    // motor + audio
    sendMotorCommand(cents);
    playInTuneBeepIfNeeded(inTune);

    bool changed = true; //so the first time pitch is detected it can get through 

    if (changed) {
      drawTuningScreen(target.name, hzRounded, centsRounded, status);

      strcpy(lastNoteName, target.name);
      strcpy(lastStatus, status);
      lastCentsRounded = centsRounded;
      lastHzRounded    = hzRounded;
      lastHadSignal    = true;
    }
    changed =
      (strcmp(target.name, lastNoteName) != 0) ||
      (strcmp(status,      lastStatus)   != 0) ||
      (centsRounded != lastCentsRounded) ||
      (hzRounded    != lastHzRounded)    ||
      !lastHadSignal;
  } else {
    // no valid frequency
    sendMotorCommand(0.0);
    playInTuneBeepIfNeeded(false);

    if (lastHadSignal||firstTimeMotor) {
      drawNoSignal();
      lastHadSignal = false;

      if (now - lastPrintMs > 200) {
        lastPrintMs = now;
      }
    }
  }
  firstTimeMotor = false;
}
void fork() {
 

  if (CircuitPlayground.rightButton()||firstTimeFork) { 
    firstTimeFork = false;
    drawCurrentNoteScreen();
    currentStringIndex++;
    if (currentStringIndex >= NUM_STRINGS) {
      currentStringIndex = 0;
    }
    delay(200);
  }
  playCurrentNotePulse();
}
void Title_Screen() {
  oled.setTextColor(0xFFFF, 0x0000);
  oled.setCursor(2, 10);
  oled.print("Welcome");
  oled.setCursor(2, 25);
  oled.print("Press L to Select Mode");
}
void Selection_Mode() {
  const char* modes[3] = {"Normal Mode", "Fork Mode", "Motor Mode"}; // FOR SELECTED MODE: normal mode = 0 Fork Mode =1 Motor Mode = 2 (could turn into enum)

  oled.setCursor(2, 10);
  oled.setTextColor(0xFFFF); // white title
  oled.print("Select Mode:");

  for (int i = 0; i < 3; i++) {
    int y = 25 + i * 10;
    oled.setCursor(2, y);

    if (i == selected_Mode) {
      oled.setTextColor(0x001F, 0xFFFF); // blue text 
    } else {
      oled.setTextColor(0xFFFF, 0x0000); 
    }
    oled.print(modes[i]);
  }
}

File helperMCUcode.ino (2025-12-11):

#include <Adafruit_TinyUSB.h>

// Motor driver pins (to driver)
#define AIN1 A1   // PWM-capable pin
#define AIN2 A2   // PWM-capable pin
#define SLP  A3   // driver enable (sleep)

// Control pins from master (CP Classic)
#define DIR_IN  A5   // HIGH = tighten, LOW = loosen
#define EN_IN   A6   // HIGH = motor on, LOW = motor off

const int MOTOR_SPEED = 200;   // 0–255, constant speed

void setup() {
  Serial.begin(115200);
  Serial.println("Bluefruit Motor Slave - DIR/EN control");

  // Control inputs from master
  pinMode(DIR_IN, INPUT);
  pinMode(EN_IN, INPUT);

  // Motor driver outputs
  pinMode(AIN1, OUTPUT);
  pinMode(AIN2, OUTPUT);
  pinMode(SLP, OUTPUT);

  digitalWrite(SLP, HIGH);  // enable motor driver

  // Ensure motor is stopped at start
  analogWrite(AIN1, 0);
  analogWrite(AIN2, 0);
}

void loop() {
  int en  = digitalRead(EN_IN);
  int dir = digitalRead(DIR_IN);

  if (en == LOW) {
    // STOP motor
    analogWrite(AIN1, 0);
    analogWrite(AIN2, 0);
  } else {
    // RUN motor at constant speed
    if (dir == HIGH) {
      // TIGHTEN direction
      analogWrite(AIN1, MOTOR_SPEED);
      analogWrite(AIN2, 0);
    } else {
      // LOOSEN direction
      analogWrite(AIN1, 0);
      analogWrite(AIN2, MOTOR_SPEED);
    }
  }

  // Optional: tiny delay to chill
  // delay(5);
}

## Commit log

2025-12-10 Add Arduino reference to references.md
2025-12-10 Create Bill of Materials with itemized costs
    Added a Bill of Materials with item details and total cost.
2025-12-10 Add Material link to index.md
2025-12-10 Add URLs to items in Material.md
    Updated item links in the material list to include URLs.
2025-12-10 Add Bill of Materials to index.html
    Added a Bill of Materials section with items and costs.
2025-12-10 Remove Bill of Materials from index.md
    Removed the Bill of Materials section including budget and itemized list.
2025-12-10 Update Bill of Materials with new item links
2025-12-10 Change Material link from .md to .html
2025-12-10 Convert Bill of Materials to HTML table format
2025-12-10 Expand ethics section with impact considerations
    Added ethical considerations regarding environmental impact, power consumption, and user privacy to the project documentation.
2025-12-10 Add detailed issues and challenges section
    Documented various issues encountered during development, including microphone reliability, pitch detection difficulties, OLED display configuration, and program storage limitations.
2025-12-10 Revise team section and fix link to Materials
    Updated team introduction and corrected materials link.
2025-12-10 Remove duplicate 'Materials' link in index.md
    Removed duplicate link to 'Materials' in HTML format.
2025-12-10 Rename 'Materials' link to 'Methods'
2025-12-10 Fix image file names to match case sensitivity
2025-12-10 Add motor control code for Bluefruit Secondary MCU
2025-12-10 Enhance Methods.md with detailed project documentation
    Expanded the Methods.md file to include detailed sections on hardware overview, pin assignments, software libraries, and guitar string representation for the guitar tuner project.
2025-12-10 Update motor control description in Methods.md
2025-12-10 Revise Methods.md for clarity and detail
    Updated the Methods.md file to clarify the implementation details of the guitar tuner, including hardware configuration, software architecture, and user interaction. Enhanced explanations for the pit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
2025-12-10 Update Methods.md to remove implementation details
    Removed mention of pitch detection logic and motor automation implementation.
2025-12-10 Document tuner thresholds in Methods.md
    Add explanation of tuner thresholds and noise filtering.
2025-12-10 Clean up code by removing commented lines
    Removed commented-out print statements and cleaned up code structure.
2025-12-10 Refactor motor command logic for clarity
2025-12-10 Document motor strength issues in project
    Added section on motor strength challenges and limitations.
2025-12-10 Revise Bill of Materials formatting and content
    Updated the Bill of Materials section with improved headings and additional context.
